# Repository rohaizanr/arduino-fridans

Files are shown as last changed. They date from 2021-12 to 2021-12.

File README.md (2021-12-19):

# Ikea Fridans Hack with Arduino (Apple Homekit)

Youtube Demo (http://www.youtube.com/watch?v=kbCUUS7IowI)

The reason why I created this project is to be able to control my Ikea Fridans Blinds using my iPhone and Siri. Please excuse my wiring diagrams and mechanical designs because I'm not an Electrical nor a Mechanical Engineer. I spent about a month researching on how to connect these things through Google and Youtube videos. Please help correct my mistakes if you find any by submitting pull requests. Thank you.

## Introduction
This guide is specifically meant for ARDUINO UNO R3 ATMEGA328P ESP8266. It is a dual core Arduino with build in Wifi. The ATMEGA328P core will be used to control the stepper motors, while the ESP8266 core will be used to handle Wifi communication and Apple Homekit. Both of these cores communicates with each other using the onboard Serial.

## Software Requirement
1. Arduino IDE (https://www.arduino.cc/en/software)
2. Arduino-HomeKit-ESP8266 (https://github.com/Mixiaoxiao/Arduino-HomeKit-ESP8266)
3. AccelStepper (https://www.arduino.cc/reference/en/libraries/accelstepper/)

## Hardware Requirements
If you wish to purchase the same hardware as I am, just copy paste the item name and find it at your nearest online store.
1. ARDUINO UNO R3 ATMEGA328P+ESP8266
2. CNC Shield V3
3. A4988 Stepper Motor Driver Module (x2)
4. NEMA 17HS4401 Bipolar Stepper Motor (x2)
5. Custom V-Pulley
    - [stepper-v6.stl](https://github.com/rohaizanr/arduino-fridans/tree/Main/3D)
    - [fridans-v6.stl](https://github.com/rohaizanr/arduino-fridans/tree/Main/3D)
6. 3mm Polyurethane Round Belt 
7. AC-DC Adapter 12V 2A
8. LED
9. Nema 17 stepper motor bracket 42 L Mounting Bracket Mount
10. Ikea Fridans Block-out roller blind
 
## Software Installation
Explain about Arduino dip switches. (todo) 

### FRIDANS_UNO
- Load FRIDANS_UNO.ino using Arduino IDE.
- Select model Arduino UNO.
- Set dip switch pin to ON 3,4.
- Load AccelStepper library.
- The stepper motor needs 200 pulses to complete make a complete rotation. My windows blinds needs 11 rotation to open and close, therefore, I need 2200 pulses to open or close my window blinds.
- Upload

### FRIDANS_ESP8266
- Load FRIDANS_ESP8266.ino using Arduino IDE.
- Select model Generic ESP8266 module.
- Set dip switch pin to ON 5,6,7.
- Load Arduino-HomeKit-ESP8266 library.
- Set home wifi password in wifi.h
- Upload

Once uploaded set 1,2 ON to enable serial communication between the 2 cores.

## Hardware Installation
(todo)

## Credits
Special thanks to my wife who have helped me with this project. My daughter, Ayesha for helping me out with the Math calculations and code debugging. My friends, Van Chiang & Ezni, for helping me print the 3D pulley and contributing to this project. Lastly, to the technical support staffs of http://my.cytron.io

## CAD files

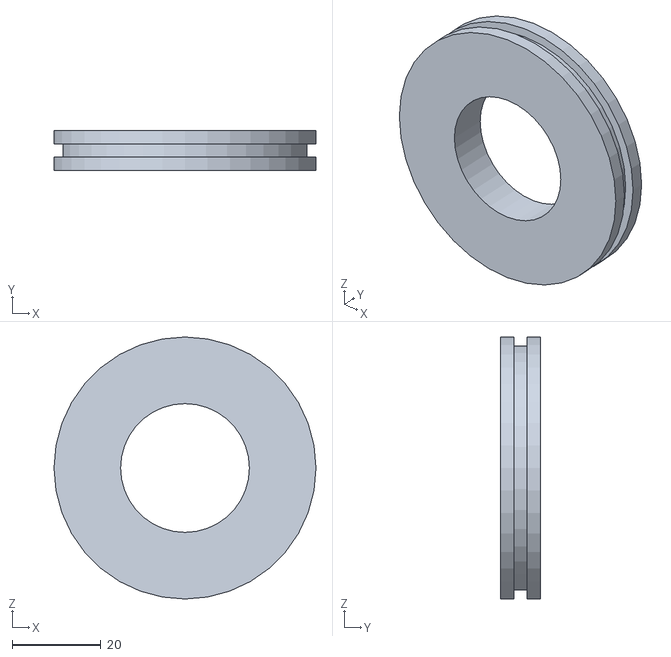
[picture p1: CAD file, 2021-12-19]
3D/fridans-v6.stl
59.0 x 9.00 x 59.0

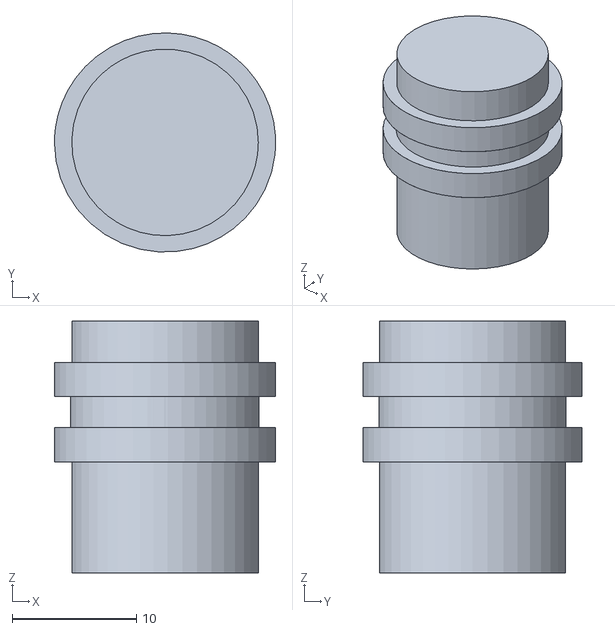
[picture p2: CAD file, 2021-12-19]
3D/stepper-v6.stl
17.8 x 17.6 x 20.3

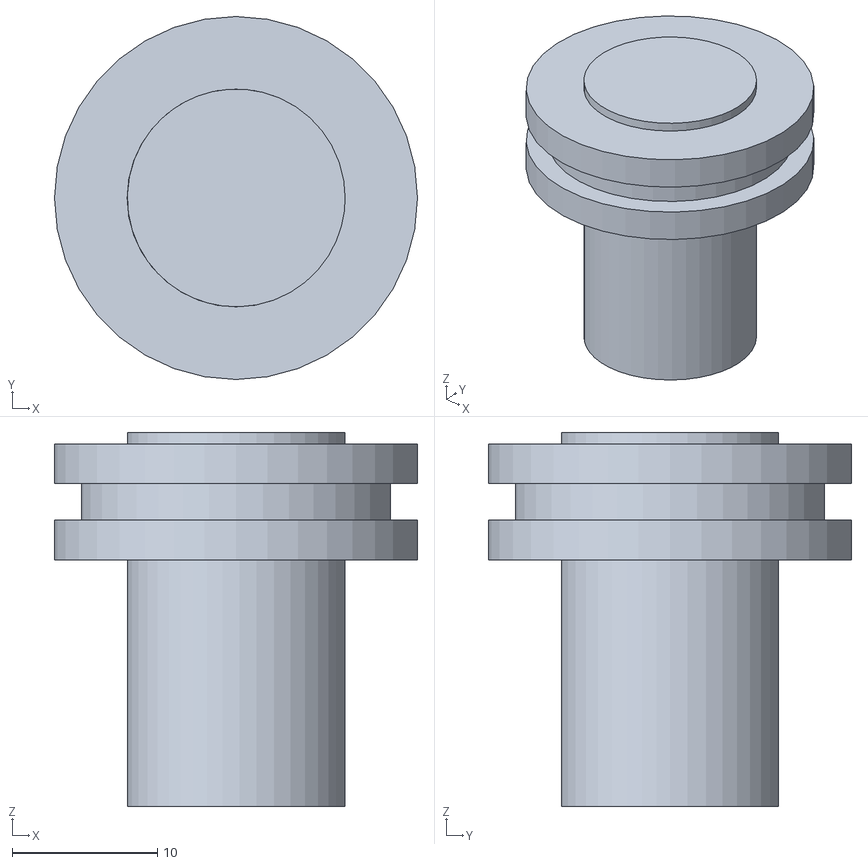
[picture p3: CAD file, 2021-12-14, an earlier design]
3D/stepper-v3.stl
25.0 x 25.0 x 25.8

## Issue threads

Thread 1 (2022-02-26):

3d parts and stepper motor assembly

kaan-37, 2022-02-26:
Hi. I did not understand how you assembled the 3d parts and stepper motors. Where did you install the Fridans?

rohaizanr, 2022-02-27:
Take a look at this.

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

rohaizanr, 2022-02-27:
Far angle
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

exrector, 2022-10-23:
@rohaizanr  Sorry. Could you make a similar circuit (working example) for ULN 2003 28BYJ-48?

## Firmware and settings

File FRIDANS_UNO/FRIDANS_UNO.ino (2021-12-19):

/*
 * FRIDANS_UNO.ino
 *
 *  Created on: 2021-11-26
 *      Author: Rohaizan Roosley
 *
 */
#include <AccelStepper.h>

// Wifi Ready Pin
#define WIFI_READY_PIN 12

// Stepper Motor X
#define MOTOR_X_ENABLE_PIN 8
#define MOTOR_X_STEP_PIN 2
#define MOTOR_X_DIR_PIN 5
AccelStepper motorX(1, MOTOR_X_STEP_PIN, MOTOR_X_DIR_PIN);

// Stepper Motor Y
#define MOTOR_Y_ENABLE_PIN 9
#define MOTOR_Y_STEP_PIN 3
#define MOTOR_Y_DIR_PIN 6
AccelStepper motorY(1, MOTOR_Y_STEP_PIN, MOTOR_Y_DIR_PIN);

// I need 10 revolutions to open/close the window blinds, therefore (12 * 200) * 3 (gear ratio)
const int MAX_STEPPER_POSITION=7200;

// Serial communication
bool dataIn = false;
String receivedCommand = "";
bool motorXBusy = false;
bool motorYBusy = false;
bool homekitXUpdated = true;
bool homekitYUpdated = true;

void setup()
{
  Serial.begin(115200);

  pinMode(WIFI_READY_PIN, OUTPUT);
  pinMode(MOTOR_X_ENABLE_PIN, OUTPUT);
  pinMode(MOTOR_Y_ENABLE_PIN, OUTPUT);

  motorX.setEnablePin(MOTOR_X_ENABLE_PIN);
  motorX.setAcceleration(250);
  motorX.setMaxSpeed(500);
  motorX.enableOutputs();
  motorX.setCurrentPosition(0);

  motorY.setEnablePin(MOTOR_Y_ENABLE_PIN);
  motorY.setAcceleration(250);
  motorY.setMaxSpeed(500);
  motorY.enableOutputs();
  motorY.setCurrentPosition(0);
}

void loop()
{
  readSerial();
  stepperLoop();
}

void stepperLoop()
{
  motorX.run();
  if (!motorX.isRunning() && !homekitXUpdated)
  {
    int homekitValue = stepperPositionToHomekitValue(motorX.currentPosition());
    Serial.print("[xfinish.position:");
    Serial.print(homekitValue);
    Serial.print("]");
    motorXBusy = false;
    homekitXUpdated = true;
  }

  motorY.run();
  if (!motorY.isRunning() && !homekitYUpdated)
  {
    int homekitValue = stepperPositionToHomekitValue(motorY.currentPosition());
    Serial.print("[yfinish.position:");
    Serial.print(homekitValue);
    Serial.print("]");
    motorYBusy = false;
    homekitYUpdated = true;
  }
}

void moveX(int homekitPositionX)
{
  motorXBusy = true;
  homekitXUpdated = false;
  int position = homekitValueToStepperPosition(homekitPositionX);

  motorX.moveTo(position);
}

void moveY(int homekitPositionY)
{
  motorYBusy = true;
  homekitYUpdated = false;
  int position = homekitValueToStepperPosition(homekitPositionY);

  motorY.moveTo(position);
}

int homekitValueToStepperPosition(int targetPosition)
{
  int step = (targetPosition == 0) ? 0 : MAX_STEPPER_POSITION / 100;
  return targetPosition * step;
}

int stepperPositionToHomekitValue(int position)
{
  float result = (position == 0) ? 0 : ((float)position / (float)MAX_STEPPER_POSITION) * 100;
  result = round(result);
  return (int)result;
}

void readSerial()
{
  while (Serial.available())
  {
    char c = Serial.read();
    if (c == '[')
    {
      receivedCommand = "";
      dataIn = true;
    }
    else if (dataIn && c != ']')
    {
      receivedCommand += c;
    }
    else if (dataIn && c == ']')
    {
      if (receivedCommand.substring(0, 17).equals("homekitPositionX:"))
      {
        int targetPositionX = receivedCommand.substring(17, receivedCommand.length()).toInt();
        int currentPositionX = stepperPositionToHomekitValue(motorX.currentPosition());
        
        if (targetPositionX != currentPositionX && !motorXBusy)
        {
          moveX(targetPositionX);
        }
      }
      else if (receivedCommand.substring(0, 17).equals("homekitPositionY:"))
      {
        int targetPositionY = receivedCommand.substring(17, receivedCommand.length()).toInt();
        int currentPositionY = stepperPositionToHomekitValue(motorY.currentPosition());
        
        if (targetPositionY != currentPositionY && !motorYBusy)
        {
          moveY(targetPositionY);
        }
      }
      else if (receivedCommand.substring(0, 17).equals("isWifiConnection:"))
      {
        int status = receivedCommand.substring(17, receivedCommand.length()).toInt();
        
        (status == 0) ? digitalWrite(WIFI_READY_PIN, LOW) : digitalWrite(WIFI_READY_PIN, HIGH);
      }
    }
  }
}

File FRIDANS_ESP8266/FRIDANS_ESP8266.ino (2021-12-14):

/*
 * FRIDANS_ESP8266.ino
 *
 *  Created on: 2021-11-26
 *      Author: Rohaizan Roosley
 *
 */

#include <Arduino.h>
#include <arduino_homekit_server.h>
#include "wifi_info.h"

// Serial communications
bool dataIn = false;
String receivedCommand = "";

// Homekit
extern "C" homekit_server_config_t config;
extern "C" homekit_characteristic_t cha_current_position_x;
extern "C" homekit_characteristic_t cha_target_position_x;
extern "C" homekit_characteristic_t cha_position_state_x;
extern "C" homekit_characteristic_t cha_current_position_y;
extern "C" homekit_characteristic_t cha_target_position_y;
extern "C" homekit_characteristic_t cha_position_state_y;

void setup()
{
  Serial.begin(115200);
  Serial.setRxBufferSize(32);
  Serial.setDebugOutput(false);
  wifi_connect();
  //homekit_storage_reset(); 
  my_homekit_setup();
}

void loop()
{
  my_homekit_loop();
  readSerial();
  wifi_status();
}

void my_homekit_setup()
{
  cha_target_position_x.setter = cha_target_position_x_set;
  cha_target_position_y.setter = cha_target_position_y_set;
  arduino_homekit_setup(&config);
  homekit_characteristic_notify(&cha_target_position_x, cha_target_position_x.value);
  homekit_characteristic_notify(&cha_target_position_y, cha_target_position_y.value);
}

void my_homekit_loop()
{
  arduino_homekit_loop();
}

void cha_target_position_x_set(const homekit_value_t value)
{
  cha_target_position_x.value.uint8_value = value.uint8_value;
  Serial.print("[homekitPositionX:");
  Serial.print(value.uint8_value);
  Serial.print("]");
}

void cha_target_position_y_set(const homekit_value_t value)
{
  cha_target_position_y.value.uint8_value = value.uint8_value;
  Serial.print("[homekitPositionY:");
  Serial.print(value.uint8_value);
  Serial.print("]");
}

void readSerial()
{
  while (Serial.available())
  {
    char c = Serial.read();
    if (c == '[')
    {
      receivedCommand = "";
      dataIn = true;
    }
    else if (dataIn && c != ']')
    {
      receivedCommand += c;
    }
    else if (dataIn && c == ']')
    {
      if (receivedCommand.substring(0, 17).equals("xfinish.position:"))
      {
        int currentPosition = receivedCommand.substring(17, receivedCommand.length()).toInt();
        uint8_t value = currentPosition;

        cha_current_position_x.value.uint8_value = value;
        cha_position_state_x.value.uint8_value = 2;

        homekit_characteristic_notify(&cha_current_position_x, cha_current_position_x.value);
        homekit_characteristic_notify(&cha_position_state_x, cha_position_state_x.value);
      }
      else if (receivedCommand.substring(0, 17).equals("yfinish.position:"))
      {
        int currentPosition = receivedCommand.substring(17, receivedCommand.length()).toInt();
        uint8_t value = currentPosition;

        cha_current_position_y.value.uint8_value = value;
        cha_position_state_y.value.uint8_value = 2;

        homekit_characteristic_notify(&cha_current_position_y, cha_current_position_y.value);
        homekit_characteristic_notify(&cha_position_state_y, cha_position_state_y.value);
      }
    }
  }
}

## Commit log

2021-12-05 Save my work
    [fridans.stl, stepper.stl]
2021-12-14 New changes
    [fridans-v3.stl, fridans.stl, stepper-v3.stl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]
2021-12-19 Latest changes
    [fridans-v3.stl, fridans-v6.stl, stepper-v5.stl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]
